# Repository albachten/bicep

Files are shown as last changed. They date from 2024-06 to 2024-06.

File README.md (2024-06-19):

# Bicep - Flexing my "ARM" muscles

This is a simple ARM Cortex M0 development board with:
* SAMD21 cpu
* 2 serial connectors
* 915MHz Hope RFM95 Lora module
* LiPo battery w/usb charger and on-off switch
* 3 I2C connectors (2 QWIIC and one pin header)

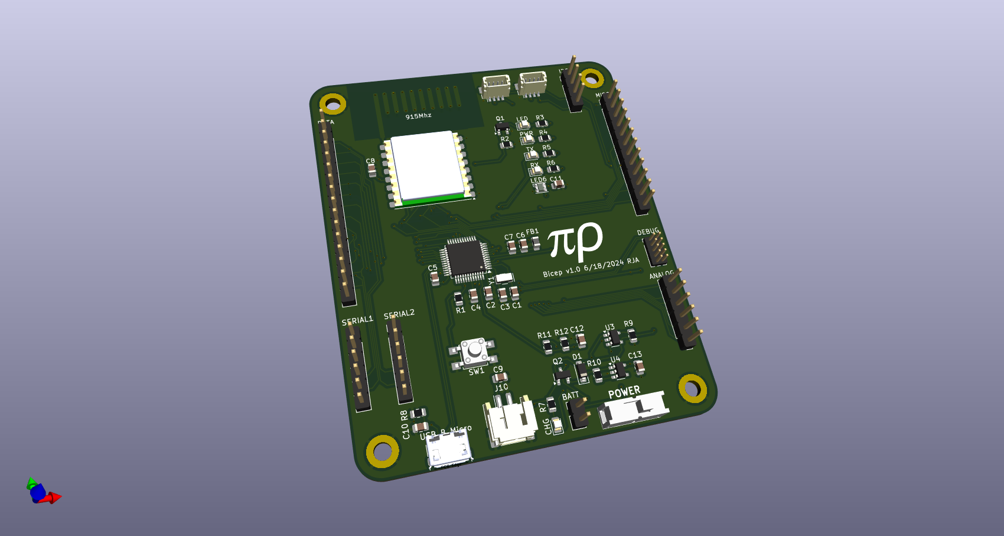
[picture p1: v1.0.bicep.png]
PCB


Schematic

[Schematic pdf](v1.0.bicep.pdf)

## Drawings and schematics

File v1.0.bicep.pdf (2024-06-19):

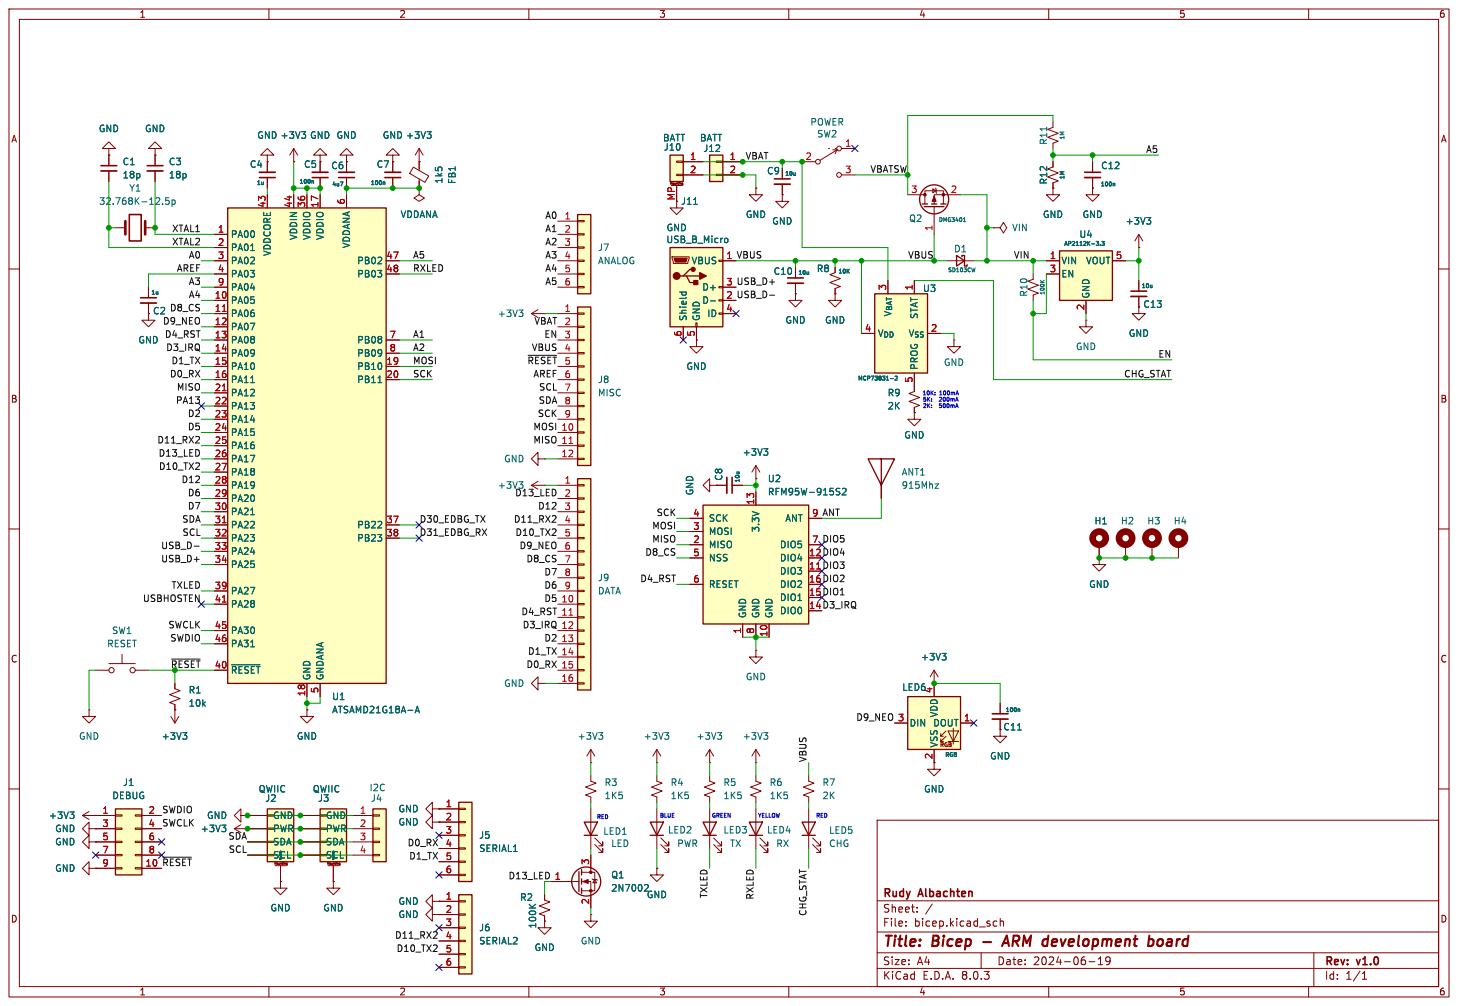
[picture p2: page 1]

1 V_{SS}2 V_{BAT} 3 V_{DD} 4 PROG

1 GND 10 DIO3 11 DIO4 12 3.3V 13 DIO0 14 DIO1 15 DIO2 16 MISO 2 MOSI 3 SCK 4 NSS 5 RESET 6 DIO5 7 GND

Id: 1/1 Title: Bicep - ARM development board

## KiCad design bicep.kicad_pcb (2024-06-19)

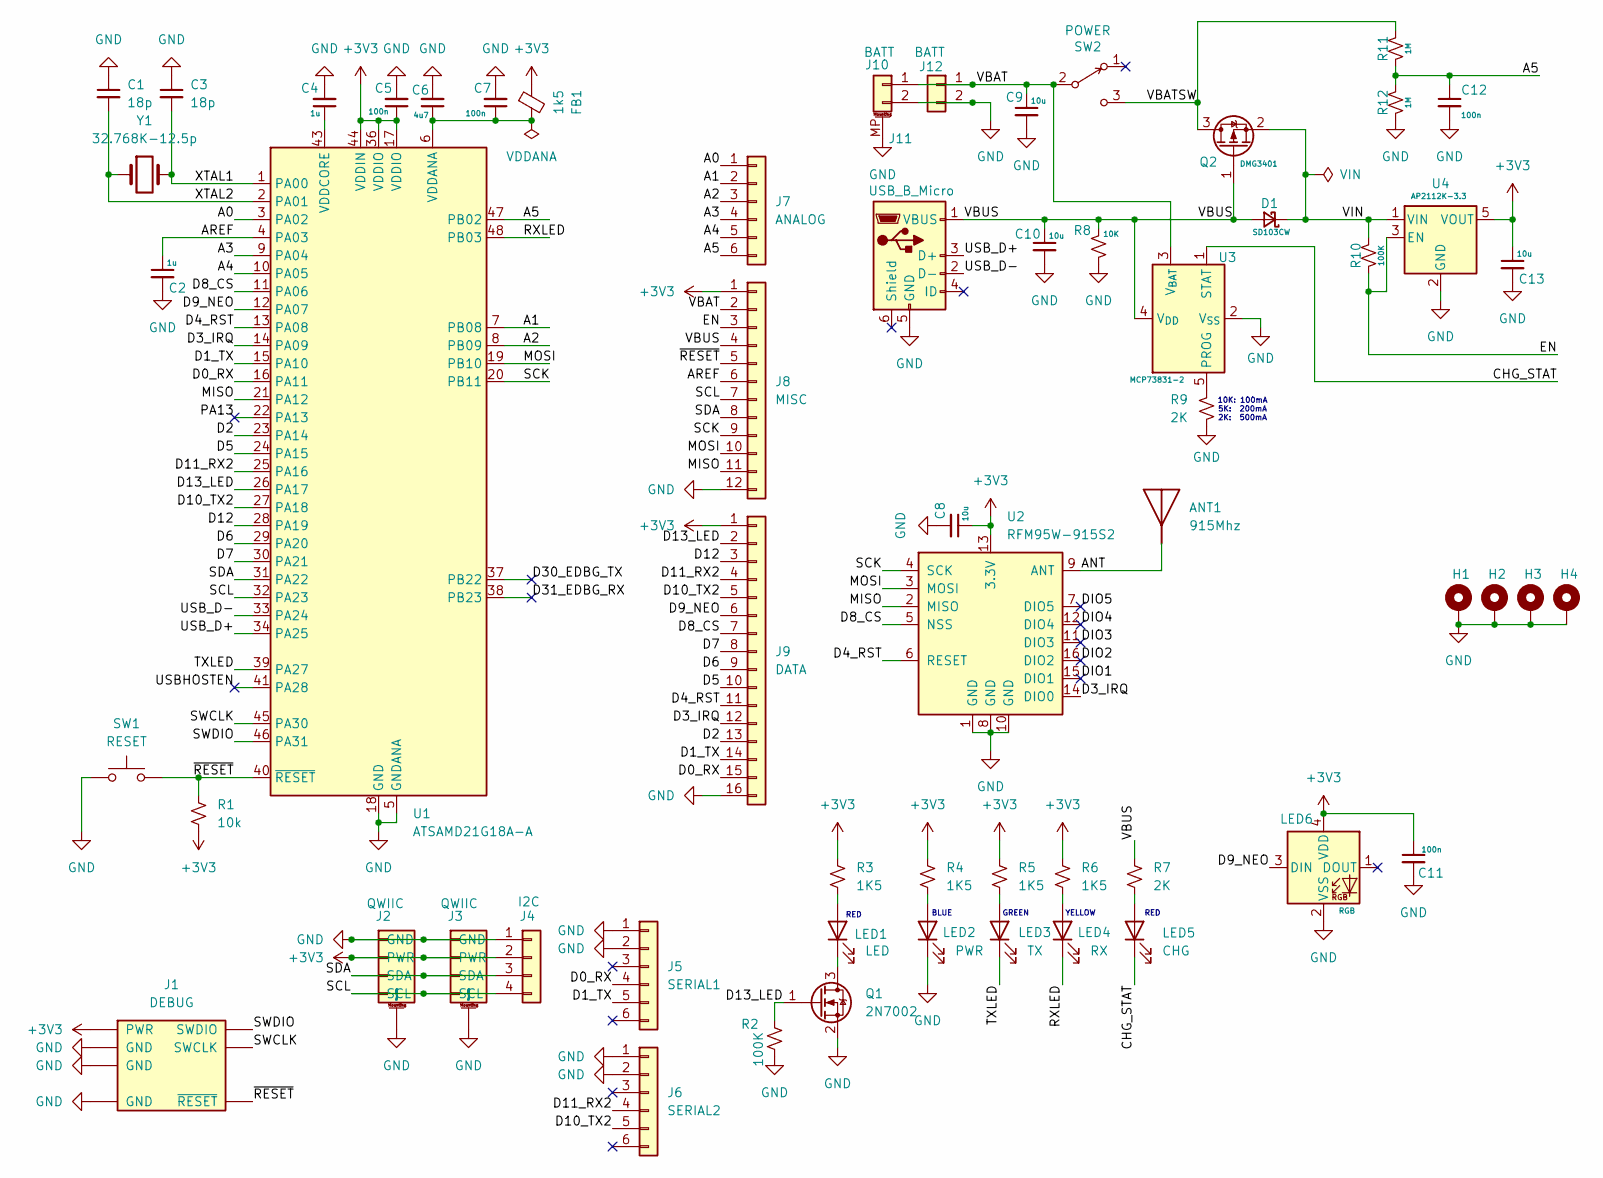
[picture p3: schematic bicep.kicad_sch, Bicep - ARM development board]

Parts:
ANT1: 915Mhz; Texas_SWRA416_868MHz_915MHz
C1, C3: 18p; C_0805_2012Metric
C2, C4: 1u; C_0805_2012Metric
C5, C7, C11, C12: 100n; C_0805_2012Metric
C6: 4u7; C_0805_2012Metric
C8, C9, C10, C13: 10u; C_0805_2012Metric
D1: SD103CW; D_SOD-123
FB1: 1k5; L_0805_2012Metric
H1, H2, H3, H4: MountingHole_Pad; MountingHole_3.2mm_M3_ISO7380_Pad
J1: DEBUG; CortexDebug
J2, J3: QWIIC; QWIIC_JST_SH_BM04B-SRSS-TB_1x04-1MP_P1.00mm_Vertical
J4: I2C; PinHeader_1x04_P2.54mm_Vertical
J5: SERIAL1; PinHeader_1x06_P2.54mm_Vertical
J6: SERIAL2; PinHeader_1x06_P2.54mm_Vertical
J7: ANALOG; PinHeader_1x06_P2.54mm_Vertical
J8: MISC; PinHeader_1x12_P2.54mm_Vertical
J9: DATA; PinHeader_1x16_P2.54mm_Vertical
J10: BATT; JST_PH_S2B-PH-SM4-TB_1x02-1MP_P2.00mm_Horizontal
J11: USB_B_Micro; USB_Micro-B_Amphenol_10118194_Horizontal
J12: BATT; PinHeader_1x02_P2.54mm_Vertical
LED1: LED; LED_0805_2012Metric
LED2: PWR; LED_0805_2012Metric
LED3: TX; LED_0805_2012Metric
LED4: RX; LED_0805_2012Metric
LED5: CHG; LED_0805_2012Metric
LED6: RGB; LED_WS2812B-2020_PLCC4_2.0x2.0mm
Q1: 2N7002; SOT-23
Q2: DMG3401; SOT-23
R1: 10k; R_0805_2012Metric
R2, R10: 100K; R_0805_2012Metric
R3, R4, R5, R6: 1K5; R_0805_2012Metric
R7, R9: 2K; R_0805_2012Metric
R8: 10K; R_0805_2012Metric
R11, R12: 1M; R_0805_2012Metric
SW1: RESET; TL3305B_SPST_PushButton
SW2: POWER; EG1218_SPDT_Slide_Switch
U1: ATSAMD21G18A-A; TQFP-48_7x7mm_P0.5mm
U2: RFM95W-915S2; RFM95CW
U3: MCP73831-2; SOT-23-5
U4: AP2112K-3.3; SOT-23-5
Y1: 32.768K-12.5p; Crystal_SMD_G8-2Pin_3.2x1.5mm

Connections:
+3V3: C5.1, C8.1, C11.1, C13.1, FB1.1, J1.1 (PWR), J2.2 (PWR), J3.2 (PWR), J4.2, J8.1, J9.1, LED6.4 (VDD), R1.2, R3.1, R4.1, R5.1, R6.1, U1.17 (VDDIO), U1.36 (VDDIO), U1.44 (VDDIN), U2.13 (3.3V), U4.5 (VOUT)
/A0: J7.1, U1.3 (PA02)
/A1: J7.2, U1.7 (PB08)
/A2: J7.3, U1.8 (PB09)
/A3: J7.4, U1.9 (PA04)
/A4: J7.5, U1.10 (PA05)
/A5: C12.1, J7.6, R11.1, R12.2, U1.47 (PB02)
/ANT: ANT1.1 (A), U2.9 (ANT)
/AREF: C2.1, J8.6, U1.4 (PA03)
/CHG_STAT: LED5.1 (K), U3.1 (STAT)
/D0_RX: J5.4, J9.15, U1.16 (PA11)
/D1_TX: J5.5, J9.14, U1.15 (PA10)
/D2: J9.13, U1.23 (PA14)
/D3_IRQ: J9.12, U1.14 (PA09), U2.14 (DIO0)
/D4_RST: J9.11, U1.13 (PA08), U2.6 (RESET)
/D5: J9.10, U1.24 (PA15)
/D6: J9.9, U1.29 (PA20)
/D7: J9.8, U1.30 (PA21)
/D8_CS: J9.7, U1.11 (PA06), U2.5 (NSS)
/D9_NEO: J9.6, LED6.3 (DIN), U1.12 (PA07)
/D10_TX2: J6.5, J9.5, U1.27 (PA18)
/D11_RX2: J6.4, J9.4, U1.25 (PA16)
/D12: J9.3, U1.28 (PA19)
/D13_LED: J9.2, Q1.1 (G), R2.1, U1.26 (PA17)
/D30_EDBG_TX: U1.37 (PB22)
/D31_EDBG_RX: U1.38 (PB23)
/DIO1: U2.15 (DIO1)
/DIO2: U2.16 (DIO2)
/DIO3: U2.11 (DIO3)
/DIO4: U2.12 (DIO4)
/DIO5: U2.7 (DIO5)
/EN: J8.3, R10.1, U4.3 (EN)
/MISO: J8.11, U1.21 (PA12), U2.2 (MISO)
/MOSI: J8.10, U1.19 (PB10), U2.3 (MOSI)
/PA13: U1.22 (PA13)
/RXLED: LED4.1 (K), U1.48 (PB03)
/SCK: J8.9, U1.20 (PB11), U2.4 (SCK)
/SCL: J2.4 (SCL), J3.4 (SCL), J4.4, J8.7, U1.32 (PA23)
/SDA: J2.3 (SDA), J3.3 (SDA), J4.3, J8.8, U1.31 (PA22)
/SWCLK: J1.4 (SWCLK), U1.45 (PA30)
/SWDIO: J1.2 (SWDIO), U1.46 (PA31)
/TXLED: LED3.1 (K), U1.39 (PA27)
/USBHOSTEN: U1.41 (PA28)
/USB_D+: J11.3 (D+), U1.34 (PA25)
/USB_D-: J11.2 (D-), U1.33 (PA24)
/VBAT: C9.1, J8.2, J10.1, J12.1, SW2.2 (B), U3.3 (V_{BAT})
/VBATSW: Q2.3 (D), R11.2, SW2.3 (C)
/VBUS: C10.1, D1.2 (A), J8.4, J11.1 (VBUS), Q2.1 (G), R7.1, R8.2, U3.4 (V_{DD})
/VIN: D1.1 (K), Q2.2 (S), R10.2, U4.1 (VIN)
/XTAL1: C3.2, U1.1 (PA00), Y1.2
/XTAL2: C1.2, U1.2 (PA01), Y1.1
/~RESET: J1.10 (~RESET), J8.5, R1.1, SW1.2, U1.40 (~RESET)
GND: C1.1, C2.2, C3.1, C4.2, C5.2, C6.2, C7.2, C8.2, C9.2, C10.2, C11.2, C12.2, C13.2, H1.1, H2.1, H3.1, H4.1, J1.3 (GND), J1.5 (GND), J1.9 (GND), J2.1 (GND), J2.MP (MountPin), J3.1 (GND), J3.MP (MountPin), J4.1, J5.1, J5.2, J6.1, J6.2, J8.12, J9.16, J10.2, J10.MP (MountPin), J11.5 (GND), J12.2, LED2.1 (K), LED6.2 (VSS), Q1.2 (S), R2.2, R8.1, R9.2, R12.1, SW1.1, U1.5 (GNDANA), U1.18 (GND), U1.35 (GND), U1.42 (GND), U2.1 (GND), U2.8 (GND), U2.10 (GND), U3.2 (V_{SS}), U4.2 (GND)
unnamed: LED1.2 (A), R3.2
unnamed: LED1.1 (K), Q1.3 (D)
unnamed: LED2.2 (A), R4.2
unnamed: LED3.2 (A), R5.2
unnamed: LED4.2 (A), R6.2
unnamed: LED5.2 (A), R7.2
unnamed: C6.1, C7.1, FB1.2, U1.6 (VDDANA)
unnamed: C4.1, U1.43 (VDDCORE)
unnamed: R9.1, U3.5 (PROG)

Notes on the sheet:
BLUE
GREEN
YELLOW
10K: 100mA 5K: 200mA 2K: 500mA
RED

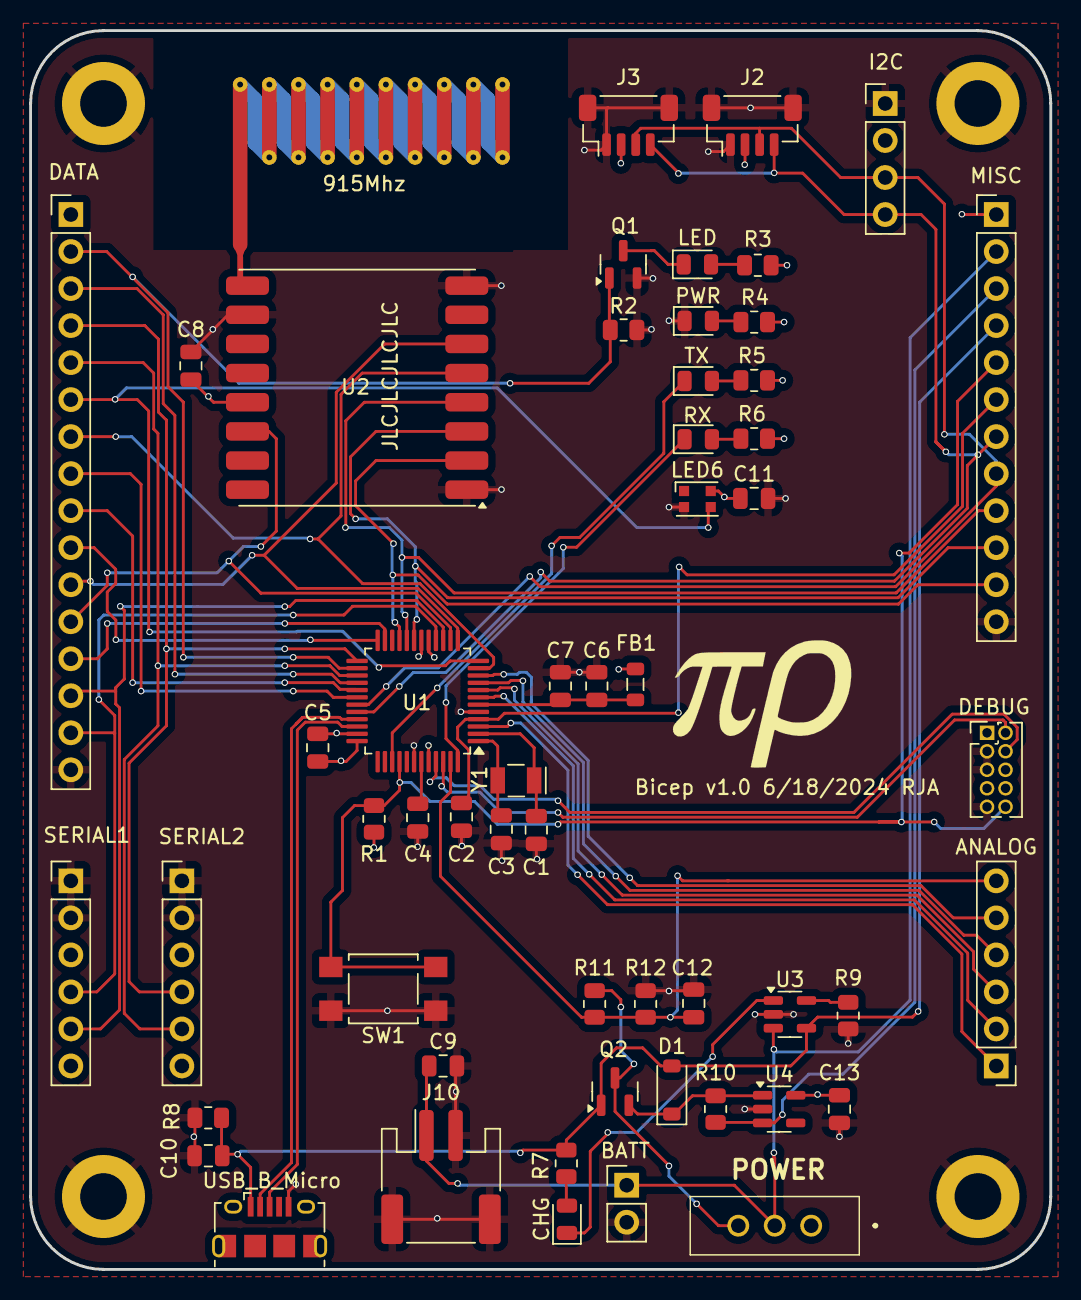
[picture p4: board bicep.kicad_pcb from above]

Board: 4 copper layers, 70.0 x 85.0 mm, 59 parts (0 on the bottom side), 53 nets.

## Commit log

2024-06-19 v1.0 initial commit
    [bicep-CuBottom.gbr, bicep-CuIn1.gbr, bicep-CuIn2.gbr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]
2024-06-19 Added shroud to 3d rendering of Cortex Debug connector
    [bicep.kicad_pcb, bicep.kicad_sch]
